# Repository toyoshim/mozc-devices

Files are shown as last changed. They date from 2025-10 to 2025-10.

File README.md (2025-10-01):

Circuit diagrams and firmware source code for Gboard DIY keyboards, previously
known as Google Japanese Input / Gboard April Fools.

This is not an officially supported Google product.

# Products

Please refer to the README in each directory for more details.

<table>
<tr>
<td>

drumset

[Google 日本語入力 ドラムセットバージョン](https://archive.google/drumsetkeyboard/)<br>
[Google Japanese Input Drum set version](https://archive.google/drumsetkeyboard/)

変換の煩わしさを感じさせない思いどおりの日本語入力を提供します。

- [Announce](https://blog.google/intl/ja-jp/products/android-chrome-play/2010_04_google/)
- Release date: Apr 1, 2010
- Source: Not open source

</td>
<td>

morse

[Google 日本語入力 モールスバージョン](http://www.google.co.jp/ime/-.-.html)<br>
[Google Japanese Input Morse version](http://www.google.co.jp/ime/-.-.html)

モールス符号で思いどおりの日本語入力

- [Promotional video](https://www.youtube.com/watch?v=u5AYb778pwA)
- [Announce](https://japan.googleblog.com/2012/04/google.html)
- [Technical details](http://googledevjp.blogspot.jp/2012/06/google.html)
- Release date: Apr 1, 2012
- Source: [/third_party/mozc-morse](./third_party/mozc-morse)

</td>
</tr>
<tr>
<td>

flap

[Google 日本語入力 パタパタバージョン](http://www.google.co.jp/ime/patapata/)<br>
[Google Japanese Input Patapata version](http://www.google.co.jp/ime/patapata/)

もう、なにも覚える必要はありません。
押して離すだけの日本語入力。

- [Promotional video](https://www.youtube.com/watch?v=HzUDAaYMNsA)
- [Announce](https://japan.googleblog.com/2013/04/google-patapata.html)
- [Technical details](http://googledevjp.blogspot.jp/2013/10/google.html)
- Release date: Apr 1, 2013
- Source: [/third_party/mozc-flap](./third_party/mozc-flap)

</td>
<td>

magichand

[Google 日本語入力 マジックハンドバージョン](https://archive.google/ime/m9/)<br>
[Google Japanese Input Magic hand version](https://archive.google/ime/m9/)

マジックハンドでらくらく入力

- [Promotional video](https://www.youtube.com/watch?v=0u1zoaJYAmw)
- [Announce](https://blog.google/intl/ja-jp/products/android-chrome-play/2014_04_m9/)
- Release date: Apr 1, 2014
- Source: Not open source

</td>
</tr>
<tr>
<td>

piropiro

[Google 日本語入力 ピロピロバージョン](https://www.google.co.jp/ime/___o/)<br>
[Google Japanese Input Piropiro version](https://www.google.co.jp/ime/___o/)

もうキーはいらない

- [Promotional video](https://www.youtube.com/watch?v=gAgOnQqyDz0)
- [Announce](https://japan.googleblog.com/2015/04/piropiro.html)
- Release date: Apr 1, 2015
- Source: [/mozc-piropiro](./mozc-piropiro)

</td>
<td>

furikku

[Google 日本語入力 物理フリックバージョン](https://www.google.co.jp/ime/furikku/)<br>
[Google Japanese Input Physical Flick version](https://www.google.co.jp/ime/furikku/)

さわれるフリック

- [Promotional video](https://www.youtube.com/watch?v=5LI1PysAlkU)
- [Announce](https://japan.googleblog.com/2016/04/furikku.html)
- Release date: Apr 1, 2016
- Source: [/mozc-furikku](./mozc-furikku)

</td>
</tr>
<tr>
<td>

puchipuchi

[日本語入力 プチプチバージョン](https://landing.google.co.jp/ime/ooooo/)<br>
[Google Japanese Input Puchi Puchi version](https://landing.google.co.jp/ime/ooooo/)

空気のように、軽やかな入力。

- [Promotional video](https://www.youtube.com/watch?v=RkJZDvHMyTA)
- [Announce](https://japan.googleblog.com/2017/04/ooooo.html)
- Release date: Apr 1, 2017
- Source: [/third_party/mozc-puchi](./third_party/mozc-puchi)

</td>
<td>

nazoru

[Gboard 物理手書きバージョン](https://landing.google.co.jp/tegaki/)<br>
[Gboard Physical Handwriting version](https://landing.google.co.jp/tegaki/)

新しいタイプの手書き入力。

- [Promotional video](https://www.youtube.com/watch?v=guJnFY1R4I0)
- [Announce](https://japan.googleblog.com/2018/04/tegaki.html)
- [Technical details](https://developers-jp.googleblog.com/2018/04/tegaki.html)
- Release date: Apr 1, 2018
- Source: [/mozc-nazoru](./mozc-nazoru)

</td>
</tr>
<tr>
<td>

mageru

[Gboard スプーン曲げバージョン](https://landing.google.co.jp/---o/)<br>
[Gboard Spoon Bending version](https://landing.google.co.jp/---o/)

タネも仕掛けもない、柔軟な入力。

- [Promotional video](https://www.youtube.com/watch?v=DeJY5d14qKs)
- [Announce](https://japan.googleblog.com/2019/04/mageru.html)
- Release date: Apr 1, 2019
- Source:
  - [/mozc-mageru](./mozc-mageru) for firmware, schematics, and PCB layout.
  - [/third_party/mozc-mageru](./third_party/mozc-mageru) for 3D model.

</td>
<td>

yunomi

[Gboard 湯呑みバージョン](https://g.co/yunomi/)<br>
[Gboard yunomi version](https://g.co/yunomi/)

もう、おすしかない。

- [Promotional video](https://www.youtube.com/watch?v=20pC05yisRM)
- [Announce](https://japan.googleblog.com/2021/10/gboard.html)
- Release date: Oct 1, 2021
- Source: [/mozc-yunomi](./mozc-yunomi)

</td>
</tr>
<tr>
<td>

bar

[Gboard 棒バージョン](https://g.co/____)<br>
[Gboard bar version](https://g.co/____)

キーの次はボーです。

- [Promotional video](https://www.youtube.com/watch?v=9G3DWHf1xX0)
- [Announce](https://japan.googleblog.com/2022/10/gboard-2022.html)
- Release date: Oct 1, 2022
- Source: [/mozc-bar](./mozc-bar)

</td>
<td>

caps

[Gboard 帽バージョン](https://g.co/CAPS)<br>
[Gboard CAPS version](https://g.co/CAPS)

入力は、帽険だ。

- [Promotional video](https://www.youtube.com/watch?v=6vib77CUxNM)
- [Announce](https://japan.googleblog.com/2023/10/caps.html)
- Release date: Oct 1, 2023
- Source: [/mozc-caps](./mozc-caps)

</td>
</tr>
<tr>
<td>

double sided

[Gboard 両面バージョン](https://g.co/double-sided)<br>
[Gboard double sided version](https://g.co/double-sided)

表面かと思ったら裏面でした。

- [Promotional video](https://www.youtube.com/watch?v=EHqPrHTN1dU)
- [Announce](https://blog.google/intl/ja-jp/products/android-chrome-play/gboard-2024)
- Release date: Oct 1, 2024
- Source: [/mozc-doublesided](./mozc-doublesided)

</td>
<td>

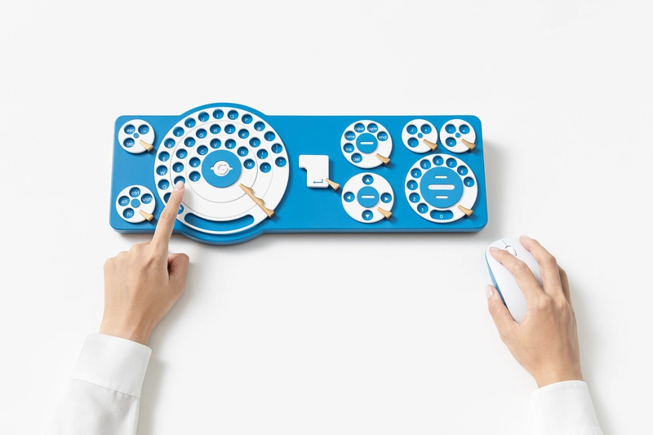
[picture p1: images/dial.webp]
dial


[Gboard ダイヤルバージョン](./mozc-dial/README_ja.md)<br>
[Gboard double sided version](./mozc-dial)

まるくおさめました。

- [Promotional video](https://youtu.be/BgdWyD0cBx4)
- [Announce](https://blog.google/intl/ja-jp/products/android-chrome-play/gboard-2025)
- Release date: Oct 1, 2025
- Source: [/mozc-dial](./mozc-dial)

</td>
</tr>
</table>

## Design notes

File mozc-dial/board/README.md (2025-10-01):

# Board Assembly Guide

For the entire keyboard assembly, please refer to the [Build Guide](../buildguide.md).

## Common to All Editions

### Sensor Board (per board)

#### Bill of Materials

| Ref | Description | Qty | Notes |
|---|---|---|---|
| R1,R3,R5 | Resistor 330Ω | 3 | Through-hole or surface-mount |
| R2,R4,R6 | Not populated | - | |
| U1-3 | Reflective photo sensor RPR-220 | 3 | (e.g., [Reflective Photo Sensor (Photoreflector) RPR-220](https://akizukidenshi.com/catalog/g/g111401/)) |
| J1 | 2.54mm pitch 1x5 pin header | 1 | L-shaped is desirable (e.g., [Pin Header (Male L-type) 1x40 (40P)](https://akizukidenshi.com/catalog/g/g101627/)) |

#### Assembly

This explanation covers the case where all 3 bits are populated. However, for the 9-dial edition, some sensors may only require 1 or 2 bits. In that case, populate only the required number of components from the top (U1). For details, follow the instructions for the 9-dial edition.

Also, before making everything, it is recommended to check if the Gray code plate values can be read properly to reduce rework in case of problems. If it doesn't work well, populate resistors on R2, R4, and R6. For details, see [Reading Sensor Adjustment](#reading-sensor-adjustment).

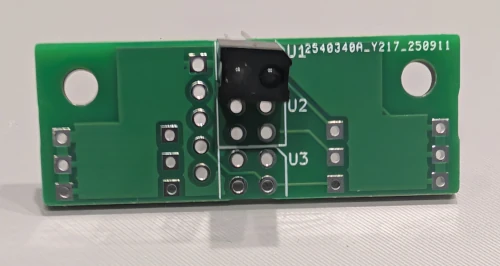
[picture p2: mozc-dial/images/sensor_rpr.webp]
Sensor RPR-220


First, attach the photo sensors from the side where the U1, U2, and U3 markings are visible. Pay close attention to the orientation. The upper right corner is chamfered, so check the marking and the shape of the sensor to ensure they are in the same orientation. After correct placement, cut off the excess leads from the back and solder them.

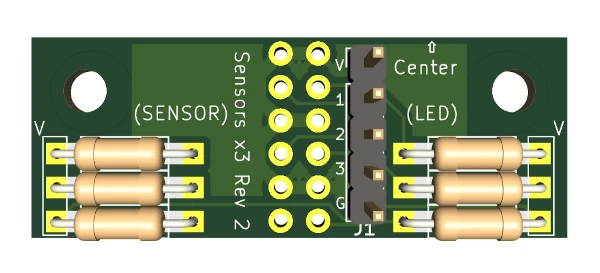
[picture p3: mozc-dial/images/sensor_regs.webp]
Sensor Resistors


On the back side, there are places to attach three resistors on the `(SENSOR)` side and three on the `(LED)` side, as shown in the figure. Both through-hole and chip resistors can be used, so use the parts of your choice. However, even for through-hole types, it is more stable to mount them without passing them through the holes when attaching the dial.

As mentioned earlier, the resistors depend on the adjustment, but it is recommended to leave the `(SENSOR)` side unpopulated and install 330Ω resistors on the `(LED)` side as a standard.

For the 1x5 pin header, using an L-shaped one will fit well in the case.

During assembly, pay attention to the `⇧Center` mark. The inner circumference of the dial will be in the direction of the arrow.

## 1-Dial Edition

This is an introductory edition that uses commercially available general-purpose parts other than the sensor board.

### Parts

- Raspberry Pi Pico: 1
- Sensor board (3-bit populated): 2
- [Unipolar Stepping Motor 28BYJ-48 5V](https://akizukidenshi.com/catalog/g/g113256/): 1
- [Stepping Motor Drive Module [M2003S]](https://www.aitendo.com/product/12366): 1
- Wiring materials: as needed

### Assembly

#### Sensor Board

Assemble two 3-bit populated sensor boards as described in the common section for all dial editions. We will call one `SENSOR L` and the other `SENSOR H`.

Although not a clean example as it was used for experiments, here are examples of mounting both through-hole and chip resistors.

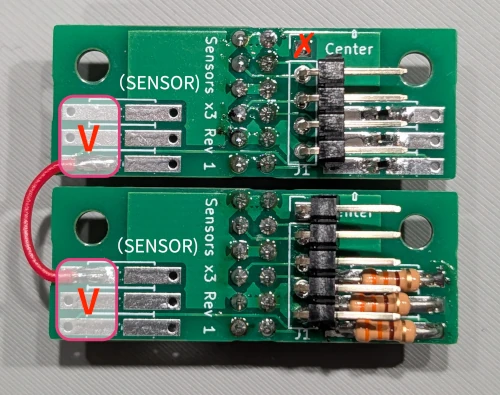
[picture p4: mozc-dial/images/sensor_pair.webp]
Sensor PCB Pair


Each board's pin header has five terminals: `V`, `1`, `2`, `3`, and `G`.
Of these, `V` connects to the 3.3V power supply, but the Raspberry Pi Pico we are using has only one 3.3V output terminal. Therefore, connect the terminal pair where `V` passes on the board, as shown by the red wiring in the photo.
In the diagram for the sensor board, the terminals inside the rectangle labeled `V`, that is, the six outer locations of the resistor patterns, are `V`.

The upper sensor board is `SENSOR L` for the inner circumference, and the lower sensor board is `SENSOR H` for the outer circumference.
Since `V` is interconnected, the `V` at the top-most, inner-most terminal is not needed for this connection.

#### Stepping Motor Drive Module

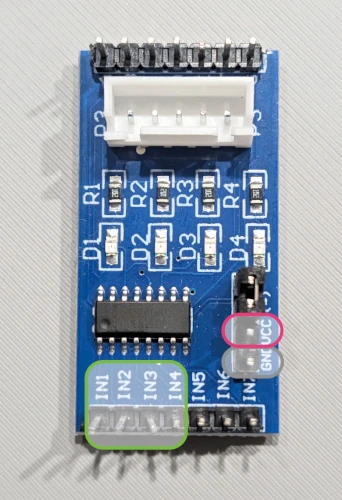
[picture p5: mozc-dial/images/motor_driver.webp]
Motor Driver


The Raspberry Pi Pico's GPIO cannot drive the motor directly, so the 1-dial edition uses a commercially available drive module. Any sink-type driver other than the one specified here will work, and you can also build your own by referring to the circuit of the 9-dial edition.

Taking the one mentioned here as an example, `IN1` to `IN4` enclosed in green are the terminals that receive the outputs `1` to `4` from the Raspberry Pi Pico. `GND` enclosed in black and `VCC` enclosed in red are `G` and `V` respectively.
The motor draws 5V power from the USB bus via the Raspberry Pi Pico. It requires about 0.3A, so the firmware for the 1-dial edition requests the 0.5A upper limit for USB micro.

The white terminal is used for connection with the stepping motor.

#### Raspberry Pi Pico

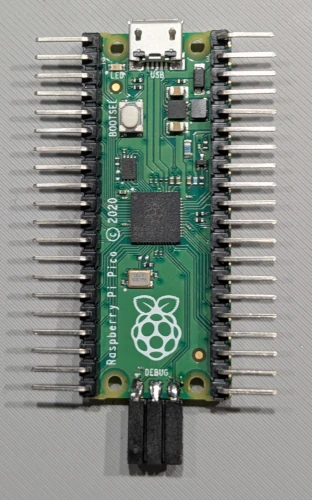
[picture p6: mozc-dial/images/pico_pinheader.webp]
Raspberry Pi Pico - Pin Headers


Attach L-shaped pin headers to a commercially available Raspberry Pi Pico as shown in the photo.
The three DEBUG pins at the bottom of the photo are optional and only needed if you need to develop and debug the firmware.

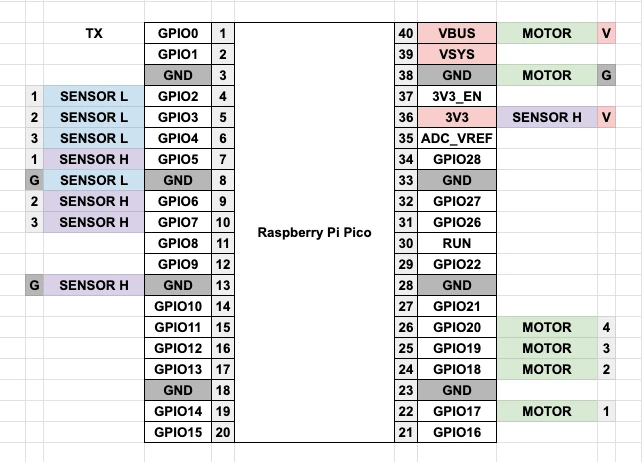
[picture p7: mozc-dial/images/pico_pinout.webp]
Raspberry Pi Pico - Pin Out


The pins used in the 1-dial edition are assigned as shown in the diagram. Connect to SENSOR L, SENSOR H, and MOTOR according to this diagram. When debugging, the standard output is output from TX via UART.

### Firmware Flashing

Follow the general method for the Raspberry Pi Pico. Connect the Raspberry Pi Pico to your PC while holding down the `BOOT` button on the board. A drive named `RPI-RP2` will appear. Copy `firmware/prebuilt/one_dial.uf2` into this drive. If the flashing is successful, the drive will disappear. Your OS may show a warning, but this is not a problem. From now on, when you connect this device to your PC without holding down the `BOOT` button, it will be recognized as a USB keyboard.

## 9-Dial Edition

### Parts

- Main board: 1
- Sensor board (3-bit populated): 6
- Sensor board (2-bit populated): 4
- Sensor board (1-bit populated): 1
- [Unipolar Stepping Motor 28BYJ-48 5V](https://akizukidenshi.com/catalog/g/g113256/): 9
- Wiring materials: as needed

### Main Board

#### Bill of Materials

| Ref | Description | Qty | Notes |
|---|---|---|---|
| C101 | Capacitor 10uF | 1 | |
| C102-121,C202-208,C212,C302-308,C312 | Capacitor 100nF | 36 | |
| C201,C209,C301,C309 | Capacitor 1uF | 4 | |
| C210,C211,C310,C311 | Capacitor 20pF | 4 | |
| J102-103 | 2.54mm pitch 1x3 pin header | 2 | |
| J106-J125 | 2.54mm pitch 1x5 pin header | 20 | |
| J201,J301 | USB TYPE C Receptacle | 2 | |
| R201-202,R301-302 | Resistor 27.4Ω | 4 | |
| R203-204,R303-304 | Resistor 5.1KΩ | 4 | |
| R205,R207,R305,R307 | Resistor 1KΩ | 4 | |
| R206,R306 | Resistor 10KΩ | 2 | |
| SW101,SW201,SW301 | Switch | 3 | |
| U101 | AMS1117 3.3V Regulator | 1 | |
| U102-103,U105,U107,U109 | TBD62083AFNG | 5 | |
| U104,U106,U108,U110 | 74HC238 | 4 | |
| U201,U301 | RP2040 | 2 | |
| U202,U302 | W25Q128JVS | 2 | |
| Y201,Y301 | 12MHz Crystal Oscillator | 2 | |
| N/A | Jumper pin | 2 | |

#### Assembly

Currently, we have released up to the schematics. We will release the Gerber data soon, so please look forward to it!

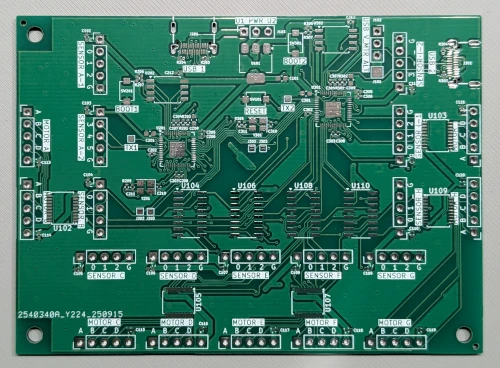
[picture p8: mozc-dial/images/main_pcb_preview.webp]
Coming Soon!!


### Assembly

Attach 1x5 L-shaped pin headers for connecting to the sensor boards to `SENSOR A-L`, `SENSOR A-H`, `SENSOR B`, `SENSOR C`, `SENSOR D`, `SENSOR E`, `SENSOR F`, `SENSOR G`, `SENSOR H`, `SENSOR I-L`, and `SENSOR I-H`.

Attach 1x5 L-shaped pin headers for connecting to the motors to `MOTOR A`, `MOTOR B`, `MOTOR C`, `MOTOR D`, `MOTOR E`, `MOTOR F`, `MOTOR G`, `MOTOR H`, and `MOTOR I`.

Attach a 1x3 pin header to the location marked `U1 PWR U2` and short the `U1` and `PWR` positions with a jumper pin.

Attach a 1x3 pin header to the location marked `USB V_MTR ALT` and short the `USB` and `V_MTR` positions with a jumper pin.

### Sensor Board

Referring to the [Common to All Dial Editions](#common-to-all-dial-editions) section, prepare a total of 11 sensor boards with the following populated bit widths. There is no problem other than an increase in standby power consumption if you populate more bits, so it is also fine to prepare all of them with a 3-bit width.

| Ref | Populated Bit Width |
|---|---|
| SENSOR A-L | 3 |
| SENSOR A-H | 3 |
| SENSOR B | 2 |
| SENSOR C | 3 |
| SENSOR D | 2 |
| SENSOR E | 3 |
| SENSOR F | 3 |
| SENSOR G | 2 |
| SENSOR H | 2 |
| SENSOR I-L | 3 |
| SENSOR I-H | 1 |

## Photo Sensor Adjustment

The photo sensor readings should not vary greatly as they are taken inside the case, but differences may arise due to the brightness of the 3D printing material or the quality of the paper on which the Gray code is printed. If the dial reading is unstable or the rotation does not stop, the sensor value change range may not be within the expected range. In that case, please adjust the sensor paying attention to the following points.

### Reading with RP2040

The sensor value is processed as a digital value by GPIO. Therefore, it needs to be adjusted so that HIGH is in the range of 2.0 - 3.3[V] and LOW is in the range of 0.0 - 0.3[V] when operating at 3.3V.

### LED Sensor Adjustment

If the current flowing through the LED is small, the light emission will be weak, and the amount of light read by the sensor will be insufficient. This will result in higher readings, and the voltage difference between white and black will not be clear. In that case, try changing the three resistors on the `(LED)` side to weaker ones. The standard is adjusted with 330Ω, but with the photo sensor RPR-220 used this time, it will stay within the rated value even if you lower it to about 40Ω. However, it will greatly affect the standby power consumption, so if possible, please adjust with the resistor on the reading sensor side.

### Reading Sensor Adjustment

You can shift the read voltage value by changing the pull-up resistance of the reading sensor. However, if you change it too much, the voltage difference between white and black will become less clear. You can adjust it by populating the three resistors on the `(SENSOR)` side. The standard firmware expects a pull-up of about 50-80KΩ by the RP2040's pull-up. If the voltage does not rise sufficiently with black, it is better to pull-up more strongly with an additional resistor. By following the [Firmware Development Guide](../firmware/README.md) and disabling the RP2040's pull-up, the resistor populated here will become the pull-up resistor. If you do not disable it, it will be pulled up by the combined resistance in parallel. The calculation is a bit complicated, but it may be easier to pull-up in parallel with an additional resistor without changing the firmware if you want to pull-up more strongly.

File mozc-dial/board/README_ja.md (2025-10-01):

# 基板組立ガイド

キーボードの組み立て全体については[ビルドガイド](../buildguide_ja.md)を参照してください。

## 各ダイヤル版共通

### センサー基板（１枚あたり）

#### 部品表

参照名 | 内容 | 数 | 備考
-------- | -------------------- | --- | ---
R1,R3,R5 | 抵抗 330Ω | 3 | スルーホール用でも表面実装用でも可
R2,R4,R6 | 未実装 | - |
U1-3 | 反射型フォトセンサー RPR-220 | 3 | （例：[反射型フォトセンサー(フォトリフレクター) RPR-220](https://akizukidenshi.com/catalog/g/g111401/)）
J1 | 2.54mmピッチ 1x5 ピンヘッダー | 1 | L字のものが望ましい（例：[ピンヘッダー (オスL型) 1×40 (40P)](https://akizukidenshi.com/catalog/g/g101627/)）

#### 実装

この説明では3ビット分全て実装する場合について説明していますが、9ダイヤル版ではセンサーによっては1ビットまたは2ビット分の実装で良い場合があります。その場合は、上(U1)から順に必要な数だけ実装してください。詳しくは9ダイヤル版の説明に従ってください。

また、すべて制作する前に、実際にグレイコード板の値が適切に読み取れるか確認し、問題がない事を確認してから作ると万が一の際の手間が軽減できます。うまくいかない場合にはR2,R4,R6に抵抗を実装します。詳しくは[読み取りセンサー調整](#読み取りセンサー調整)を確認してください。

Sensor RPR-220

まずはU1、U2、U3の印刷が見える方から、フォトセンサーを取りつけます。向きに十分気をつけて下さい。右上の角が面取りされているので、印刷面とセンサーの形状を見て、同じ向きになるよう設置してください。正しく設置したら、裏側から不要な足を切り取りハンダ付けします。

Sensor Registors

裏面はこの図のように`(SENSOR)`側に3つ、`(LED)`側に3つの抵抗を取り付けられるようになっています。抵抗はスルーホール用のものと、チップ抵抗と、いずれのタイプでも取り付けられるようになっているので、お好みいのパーツを使って取り付けてください。ただし、スルーホール用の物でも、穴には通さずに取り付けた方がダイヤル取り付け時に安定します。

抵抗については前述の通り調整に依存しますが、標準では`(SENSOR)`側は未実装、`(LED)`側に330Ωの抵抗を取り付ける事を推奨します。

また、1x5のピンヘッダーについては、L字の物を使うとケースにうまく収まります。

組立時には`⇧Center`マークに注意してください。ダイヤル内周側が矢印の方向になります。

## 1ダイヤル版

センサー基板以外は市販の汎用部品を使う入門版です。

### 部品

- Raspberry Pi Pico: 1個
- センサー基板（3bit実装）: 2個
- [ユニポーラー ステッピングモーター 28BYJ-48 5V](https://akizukidenshi.com/catalog/g/g113256/):
  1個
- [ステッピングモータドライブモジュール [M2003S]](https://www.aitendo.com/product/12366): 1個
- 配線材: 適宜

### 組み立て

#### センサー基板

各ダイヤル版共通で説明したセンサー基板を、3bit実装で2つ組み立てます。 1つを`SENSOR L`、もう1つを`SENSOR H`と呼ぶことにします。

実験時に使用したもので見本としては綺麗なものではありませんが、スルーホール型の抵抗とチップ抵抗それぞれの実装例がこちらになります。

Sensor PCB Pair

それぞれに基板のピンヘッダーには`V`、`1`、`2`、`3`、`G`の5つの端子があります。
このうち`V`は3.3V電源へ繋ぐのですが、今回利用するRaspberry Pi
Picoには3.3V出力端子は1つしかありませんので、写真の赤い配線のように基板上で`V`が通っている端子ペアを接続します。
センサー基板の説明で上げた図において`V`と書かれた長方形の内側にある端子、つまり抵抗用パターンのうち外側の6箇所が`V`になっています。

上側のセンサー基板が`SENSOR L`で内周側、下側のセンサー基板が`SENSOR H`で外周側になります。
`V`を相互接続したので、一番上の最も内側にあたる端子の`V`は今回接続不要となります。

#### ステッピングモータドライブモジュール

Motor Driver

Raspberry Pi
PicoのGPIOでは直接モーターをドライブできないため、1ダイヤル版では市販のドライブモジュールを流用します。シンクタイプのドライバなら今回指定したもの以外でも構いませんし、9ダイヤル版の回路を参考に自作する事も可能です。

今回参考に上げた物を例にすると、緑で囲んだ`IN1`〜`IN4`がRaspberry Pi
Picoからの出力の`1`〜`4`を受ける端子になります。黒で囲んだ`GND`と赤で囲んだ`VCC`がそれぞれ`G`と`V`です。
モーターの方はUSBバスから5Vの電源をRaspberry Pi
Pico経由で引き込みます。0.3Aくらい必要となるため、1ダイヤル版のファームウェアではUSB microでの上限である0.5Aを要求しています。

白い端子はステッピングモータとの接続に使います。

#### Raspberry Pi Pico

Raspberry Pi Pico - Pin Headers

市販のRaspberry Pi Picoに対して、写真のようにL字のピンヘッダーを取り付けます。
写真で下の方にあるDEBUG用のピン3つについては、ファームウェアの開発とデバッグが必要な場合のみで構いませんので、お好みで取り付けてください。

Raspberry Pi Pico - Pin Out

1ダイヤル版で使うピンについては、図のような割り当てになっています。この図に従って、SENSOR L、SENSOR
H、MOTORと接続します。デバッグ時の標準出力をUARTから出力する場合はTXから出力されます。

### ファームウェア書き込み

Raspberry Pi Picoの一般的な方法に従います。Raspberry Pi
Pico基板上の`BOOT`ボタンを押しながらPCに接続すると`RPI-RP2`という名前のドライブが出現するので、`firmware/prebuilt/one_dial.uf2`をこのドライブの中にコピーします。正しく書き込みができた場合ドライブが消えます。OSによって警告が表示されますが問題ありません。これ以降、このデバイスを`BOOT`ボタンを押さずにPCに接続した場合は、USBキーボードとして認識されるようになります。

## 9ダイヤル版

### 部品

- メイン基板: 1個
- センサー基板（3bit実装）: 6個
- センサー基板（2bit実装）: 4個
- センサー基板（1bit実装）: 1個
- [ユニポーラー ステッピングモーター 28BYJ-48 5V](https://akizukidenshi.com/catalog/g/g113256/):
  9個
- 配線材: 適宜

### メイン基板

#### 部品表

参照名 | 内容 | 数
------------------------------------ | ----------------------- | ---
C101 | コンデンサ 10uF | 1
C102-121,C202-208,C212,C302-308,C312 | コンデンサ 100nF | 36
C201,C209,C301,C309 | コンデンサ 1uF | 4
C210,C211,C310,C311 | コンデンサ 20pF | 4
J102-103 | 2.54mmピッチ 1x3 ピンヘッダ | 2
J106-J125 | 2.54mmピッチ 1x5 ピンヘッダ | 20
J201,J301 | USB TYPE C Receptacle | 2
R201-202,R301-302 | 抵抗 27.4Ω | 4
R203-204,R303-304 | 抵抗 5.1KΩ | 4
R205,R207,R305,R307 | 抵抗 1KΩ | 4
R206,R306 | 抵抗 10KΩ | 2
SW101,SW201,SW301 | スイッチ | 3
U101 | AMS1117 3.3V レギュレーター | 1
U102-103,U105,U107,U109 | TBD62083AFNG | 5
U104,U106,U108,U110 | 74HC238 | 4
U201,U301 | RP2040 | 2
U202,U302 | W25Q128JVS | 2
Y201,Y301 | 12MHz Crystal Oscilator | 2
N/A | ジャンパーピン | 2

#### 実装

現在、回路図まで公開しています。近日中にガーバーデータを公開しますのでお楽しみに！

Coming Soon!!

### 組み立て

`SENSOR A-L`、`SENSOR A-H`、`SENSOR B`、`SENSOR C`、`SENSOR D`、`SENSOR E`、`SENSOR F`、`SENSOR G`、`SENSOR H`、`SENSOR I-L`、`SENSOR I-H`それぞれに、センサー基板との接続に用いる1x5のL字型ピンヘッダを取り付けます。

`MOTOR A`、`MOTOR B`、`MOTOR C`、`MOTOR D`、`MOTOR E`、`MOTOR F`、`MOTOR G`、`MOTOR H`、`MOTOR I`についてはモーターとの接続に用いる1x5のL字型ピンヘッダを取り付けます。

`U1 PWR U2`と書かれた箇所に1x3のピンヘッダを取り付け、ジャンパーピンで`U1`と`PWR`の位置をショートします。

`USB V_MTR ALT`と書かれた箇所に1x3のピンヘッダと取り付け、ジャンパーピンで`USB`と`V_MTR`の位置をショートします。

### センサー基板

[各ダイヤル版共通](#各ダイヤル版共通)の説明を参照して、合計11個のセンサー基板をそれぞれ以下の実装ビット幅で用意します。多めに実装する分には待機時消費電力の増加以外は問題ないので、全てを3ビット幅で用意してしまっても問題はありません。

参照名 | 実装ビット幅
---------- | ------
SENSOR A-L | 3
SENSOR A-H | 3
SENSOR B | 2
SENSOR C | 3
SENSOR D | 2
SENSOR E | 3
SENSOR F | 3
SENSOR G | 2
SENSOR H | 2
SENSOR I-L | 3
SENSOR I-H | 1

## フォトセンサーの調整について

フォトセンサーの読み取り値は、ケース内での読み取りになるため大きな差は出にくいはずですが、3Dプリント素材の明るさの違いや、グレイコードを印刷した紙の質などによって違いが出てくる可能性があります。ダイヤルの読み取りが安定しない、回転が止まらないなどの症状が出ている場合にはセンサー値の変化範囲が想定内に収まっていない可能性がありますので、以下の点に注意してセンサーの調整をしてください。

### RP2040での読み取り

センサーの値はGPIOでデジタル値として処理しています。そのため、3.3V稼働時にHIGHは2.0 - 3.3[V]、LOWは0.0 -
0.3[V]の範囲に収まるよう調整されている必要があります。

### LEDセンサー調整

LEDに流れる電流が少ないと発光も弱くなり、センサーで読み取る光量も不足します。そのため、読み取り値が高くなり、白と黒で電圧差がはっきりとでなくなってきます。その場合、`(LED)`と書かれた側にある3つの抵抗を弱いものに変えてみてください。標準では330Ωで調整していますが、今回用いているフォトセンサーRPR-220では40Ωくらいまで下げても定格内に収まります。ただし、待機時の消費電力に大きく影響しますので、可能なら読み取りセンサー側の抵抗で調整してください。

### 読み取りセンサー調整

読み取りセンサーのpull-up抵抗値を変える事で、読み取る電圧値をシフトさせる事ができます。ただし、大きく変えすぎるとやはり白と黒の電圧差が出にくくなります。`(SENSOR)`と書かれた側にある3つの抵抗を実装する事で調整できます。標準のファームウェアではRP2040のpull-upにより、およそ50-80KΩでpull-upされる事を期待しています。黒で十分に電圧が上がらない場合は、追加の抵抗でより強くpull-upすると良いでしょう。[ファームウェア開発ガイド](../firmware/README_ja.md)に従いRP2040のpull-upを無効化すると、ここに実装した抵抗がそのままpull-up抵抗になります。無効化しない場合は並列接続での合成抵抗でpull-upする事になります。計算が少し煩雑ですが、より強くpull-upする分にはファームウェアを変えずに追加の抵抗で並列でpull-upする方が簡単かもしれません。

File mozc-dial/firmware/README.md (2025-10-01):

# Firmware Development Guide

For the entire keyboard assembly, please refer to the [Build Guide](../buildguide.md).

## Directory List

- prebuilt/ : Pre-built firmware for each board
- common/ : Source files for libraries used in common by each board
- main/ : Source files and project for the 9-dial edition main chip
- sub/ : Source files and project for the 9-dial edition sub chip
- one_dial/ : Source files and project for the 1-dial edition Raspberry Pi Pico

## Pre-built Firmware

We have included pre-built firmware under `prebuilt/`, so you can use them as is if no changes are needed.

Use `main.uf2` and `sub.uf2` for the 9-dial edition, and `one_dial.uf2` for the 1-dial edition.

## Guide to Developing Your Own Firmware

Install [Visual Studio Code](https://code.visualstudio.com/) and add the [Raspberry Pi Pico extension](https://marketplace.visualstudio.com/items?itemName=raspberry-pi.raspberry-pi-pico).

From the `Raspberry Pi Pico Projects` extension in the Activity Bar, use `Import Project` to open each project's directory.
If you are using the extension for the first time, the development environment installation will begin. Once the project is imported, you can develop using `CMake` and `Run and Debug` in the Activity Bar.

As with the official Pico series boards, the 9-dial edition has `SWCLK` and `SWDIO` land pairs labeled `SWC/D` on the board for each chip. By preparing development equipment that supports SWD, such as the official Debug Probe, you can perform step execution in the editor.

### Standard Output

On the 9-dial edition, there are lands labeled `TX1` for the main chip and `TX2` for the sub-chip on the board. With the standard settings, the standard output is output from these pins as UART at a speed of 115200.

On the other hand, by changing `pico_enable_stdio_uart` to `0` and `pico_enable_stdio_semihosting` to `1` in `CMakeLists.txt`, you can switch the output to go through the debugger. This is convenient as you don't need to wire TX, but be aware that the operation will stop at the output point if debugger support is not enabled. It will also stop when the debugger is not attached, so it cannot be used for release builds. Debugger support can be enabled with `monitor arm semihosting enable`, but it is tedious to set it every time you start the debugger, so it is convenient to register it in each command setting in `.vscode/launch.json` as follows.

```
"postLaunchCommands": [
    "monitor arm semihosting enable"
]
```

### Using PICO W or PICO 2 (W)

The 1-dial edition is set to use the official Raspberry Pi Pico board, but you can support other boards by changing the board setting from `pico` to `pico_w`, `pico2`, `pico2_w`, etc. in `set(PICO_BOARD pico CACHE STRING "Board type")` in `CMakeFiles.txt`. You should also be able to support 3rd party boards with `none`, etc.

### About EEPROM

Since the board setting for the 9-dial edition is `none`, a general-purpose driver for EEPROM will be included with a prescaler setting of 4. This should work with most EEPROMs. If you are using the reference parts, we have confirmed that the driver for W25Q080 works with a prescaler setting of 2, similar to the official board. By creating a `board_name.h` in `~/.pico-sdk/sdk/2.2.0/src/boards/include/boards/` and defining

```
#define PICO_BOOT_STAGE_2_CHOOSE_W25Q080 1
#define PICO_FLASH_SPI_CLKDIV 2
```

and specifying it in the board settings of `CMakeFiles.txt`, you can optimize EEPROM access via QSPI in case of a cache miss and draw out further performance.

### About Sensor Adjustment

By default, the sensor is pulled up by an internal resistor. If you want to adjust it by pulling up with an external resistor, change `gpio_pull_up(gpio);` to `gpio_disable_pulls(gpio);` in `PhotoSensor::PhotoSensor()` in `photo_sensor.cc`.

Alternatively, it is also possible to pull up with a combined resistance of the internal and external resistors while the internal resistor is enabled. In this case, the internal resistor has a nominal value of 50-80KΩ and is connected in parallel with the external resistor.

For details, please check the [Board Assembly Guide](../board/README.md).

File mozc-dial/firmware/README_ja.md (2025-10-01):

# ファームウェア開発ガイド

キーボードの組み立て全体については[ビルドガイド](../buildguide_ja.md)を参照してください。

## ディレクトリ一覧

- prebuilt/ : 各ボード向けに事前にビルドしたファームウェア
- common/ : 各ボード共通で用いられるライブラリのソースファイル
- main/ : 9ダイヤル版メインチップ用のソースファイルとプロジェクト
- sub/ : 9ダイヤル版サブチップ用のソースファイルとプロジェクト
- one_dial/ : 1ダイヤル版 Raspberry Pi Pico用のソーとファイルとプロジェクト

## 事前にビルドしたファームウェア

`prebuilt/`以下に事前にビルドしたファームウェアを収めていますので、変更が不要の場合はこれらをそのまま用いることができます。

9ダイヤル板は`main.uf2`と`sub.uf2`を、1ダイヤル板は`one_dial.uf2`を使用します。

## 独自のファームウェア開発の手引き

[Visual Studio Code](https://code.visualstudio.com/) をインストールし、[Raspberry Pi Pico拡張](https://marketplace.visualstudio.com/items?itemName=raspberry-pi.raspberry-pi-pico) を追加します。

Activity Barの`Raspberry Pi Pico Projects`の拡張機能から`Import Project`を使い、各プロジェクトのディレクトリを開いてください。
拡張をはじめて使う場合、開発環境のインストールが始まります。プロジェクトが取り込まれると、Activity Barの`CMake`や`Run and Debug`を使って開発できるようになります。

公式のPicoシリーズボードに搭載されているように、9ダイヤル板でも基板上に`SWC/D`と書かれた`SWCLK`と`SWDIO`のランドペアがそれぞれのチップごとに用意されています。公式のDebug Probe等のSWDをサポートした開発機材を用意する事で、エディタ上でステップ実効等が可能です。

### 標準出力について

9ダイヤル板では基板上にメインチップ用の`TX1`、サブチップ用の`TX2`と書かれたランドが用意されており、標準の設定では標準出力はこれらのピンから速度115200のUARTとして出力されています。

一方で`CMakeLists.txt`の`pico_enable_stdio_uart`を`0`に、`pico_enable_stdio_semihosting`を`1`に変更する事で、出力をデバッガ経由に切り替える事ができます。TXを配線せずに済むので便利ですが、デバッガのサポートを有効にしないと出力のところで動作停止するので注意が必要です。デバッガがアタッチされていない時も同様に停止するので、リリースビルドには使えません。デバッガのサポートは`monitor arm semihosting enable`で有効に出来ますが、デバッガ起動ごとに毎回設定するのは大変なので、`.vscode/launch.json`の各コマンド設定内に以下のように登録しておくと便利です。

```
"postLaunchCommands": [
    "monitor arm semihosting enable"
]
```

### PICO WやPICO 2 (W)の利用

1ダイヤル板は公式のRaspberry Pi Picoボードを使うように設定してありますが、`CMakeFiles.txt`内の`set(PICO_BOARD pico CACHE STRING "Board type")`のところでボード設定を`pico`から`pico_w`、`pico2`、`pico2_w`等に変更する事で他のボードにも対応できるかと思います。3rd party製のボードについても`none`等で対応できるかと思います。

### EEPROMについて

9ダイヤル版はボード設定を`none`にしているので、EEPROMについては汎用のドライバが分周4で組み込まれます。これでだいたいのEEPROMで動作するはずです。リファレンスの部品を使っている場合は、公式ボードと同様にW25Q080用のドライバが分周2で動作する事を確認しています。`~/.pico-sdk/sdk/2.2.0/src/boards/include/boards/`に`ボード名.h`を作成し、その中で

```
#define PICO_BOOT_STAGE_2_CHOOSE_W25Q080 1
#define PICO_FLASH_SPI_CLKDIV 2
```

などを定義し、`CMakeFiles.txt`のボード設定で指定する事で、キャッシュミス時のQSPI経由でのEEPROMアクセスを最適化し、さらなる性能を引き出す事も可能です。

### センサーの調整について

標準ではセンサーは内部抵抗でpull-upされています。外部抵抗によりpull-upで調整したい場合、`photo_sensor.cc`の`PhotoSensor::PhotoSensor()`内にある`gpio_pull_up(gpio);`を`gpio_disable_pulls(gpio);`に変更してください。

あるいは、内部抵抗を有効にしたまま外部抵抗との合成抵抗でpull-upする事も可能です。この場合、内部抵抗は公称値で50-80KΩ、外部抵抗とは並列接続になります。

詳細は[基板組立ガイド](../board/README_ja.md)を確認してください。

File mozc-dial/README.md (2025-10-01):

[Japanese version](./README_ja.md) is available.

# Gboard Dial Version

This directory contains the design data and firmware for the Gboard Dial Version, released on October 1, 2025.
The Gboard Dial Version is not an official Google product.

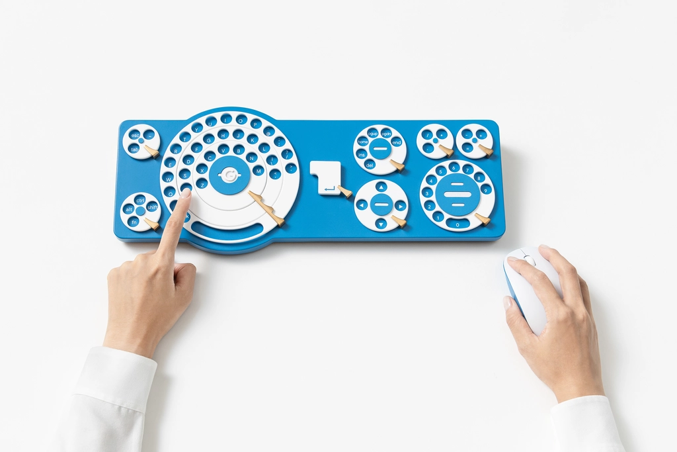
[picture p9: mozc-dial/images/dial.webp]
Gboard dial version


**We've made things well-rounded.**

"Keyboards are boring if you can only type on them."

In response to feedback from our users,

we have created a keyboard that you can turn.

The Gboard Dial Version,

realizing text input by rotation.

## Let's build it

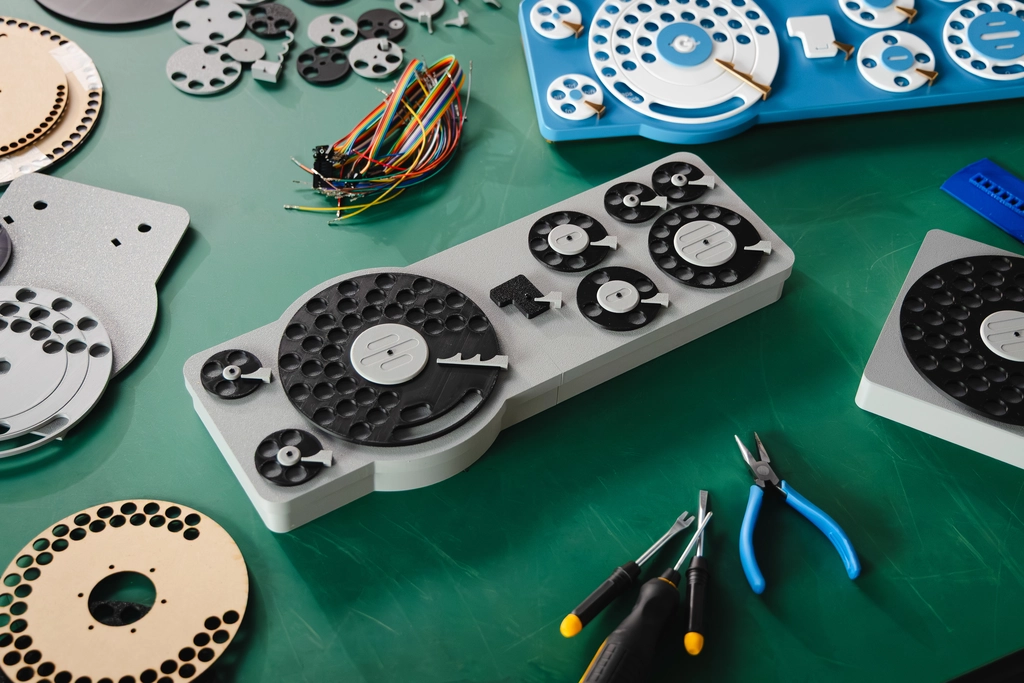
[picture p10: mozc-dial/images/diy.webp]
Gboard DIY


This year again, we are releasing 3D printing model data, board data, and firmware.

[Click here for the build guide](./buildguide.md)

## There's also a non-rotating Gboard

For those who are accustomed to conventional typing input,

we also offer the standard version of Gboard.

It provides a comfortable input experience

in conjunction with various Google services

such as voice input and translation functions.

[Available on Google Play](https://play.google.com/store/apps/details?id=com.google.android.inputmethod.latin)<br>
[Available on the App Store](https://apps.apple.com/us/app/gboard-the-google-keyboard/id1091700242)

## [Other versions](https://github.com/google/mozc-devices)

## License

See [LICENSE](../LICENSE) file in this directory.

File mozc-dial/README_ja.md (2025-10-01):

Gboard[English version](./README.md) is available.

# Gboard ダイヤルバージョン

このディレクトリは 2025 年 10 月 1 日にリリースされた Gboard ダイヤルバージョンの設計データとファームウエアを含んでいます。
Gboard ダイヤルバージョンは正式な Google 製品ではありません。

Gboard dial version

**まるくおさめました。**

「キーボードは打つだけじゃつまらない」

そんなユーザーのみなさまの声に応えて

まわす事ができるキーボードを作りました。

回転による文字入力を実現した、

Gboard ダイヤルバージョン

## 作ってみよう

Gboard DIY

今年も 3D プリント用モデルデータ、基板データ、ファームウエアを公開しています。

[ビルドガイドはこちら](./buildguide_ja.md)

## まわらないGboardもあります

いままでの打つ文字入力に慣れ親しんだ方には、

通常版の Gboard もご用意しております。

音声入力や翻訳機能など

Google の各種サービスと連携した

快適な入力体験を提供します。

[Google Play で公開中](https://play.google.com/store/apps/details?id=com.google.android.inputmethod.latin&hl=ja)<br>
[App Store で公開中](https://apps.apple.com/jp/app/id1091700242)

## [その他のバージョン](https://github.com/google/mozc-devices)

## ライセンス

このディレクトリに置かれた [LICENSE](../LICENSE) ファイルを参照してください。

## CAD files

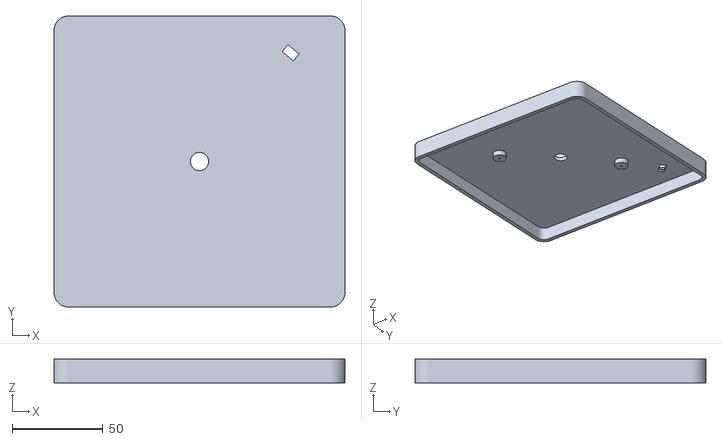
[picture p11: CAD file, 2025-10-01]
mozc-dial/stls/one_dial/case_top.stl
160.0 x 160.0 x 13.0

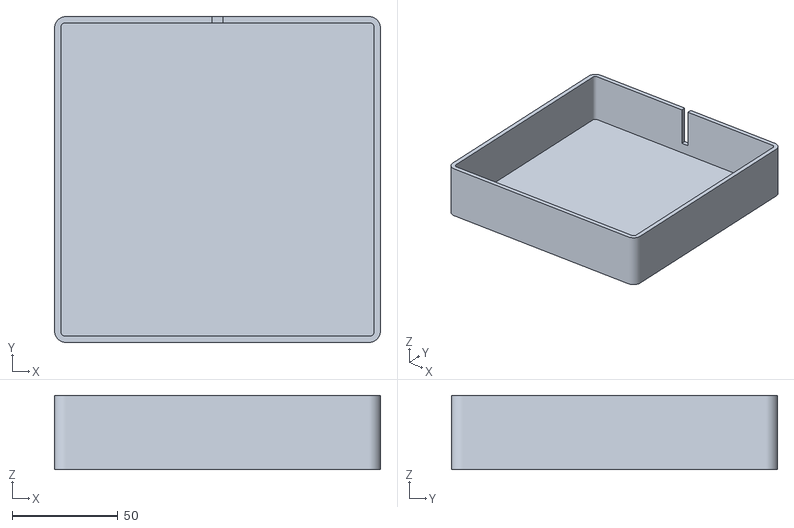
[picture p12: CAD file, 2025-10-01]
mozc-dial/stls/one_dial/case_bottom.stl
154.0 x 154.0 x 35.0

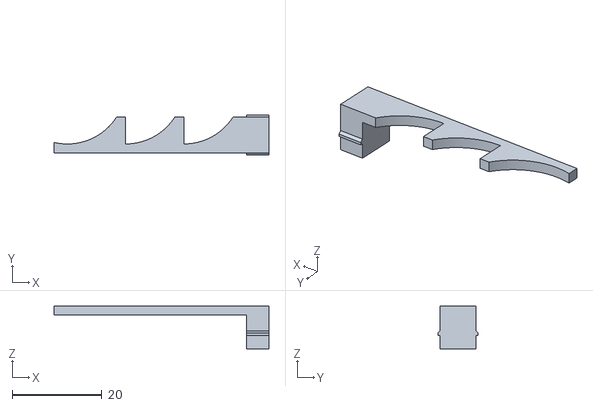
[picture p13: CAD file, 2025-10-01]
mozc-dial/stls/one_dial/end3.stl
48.0 x 9.00 x 9.50

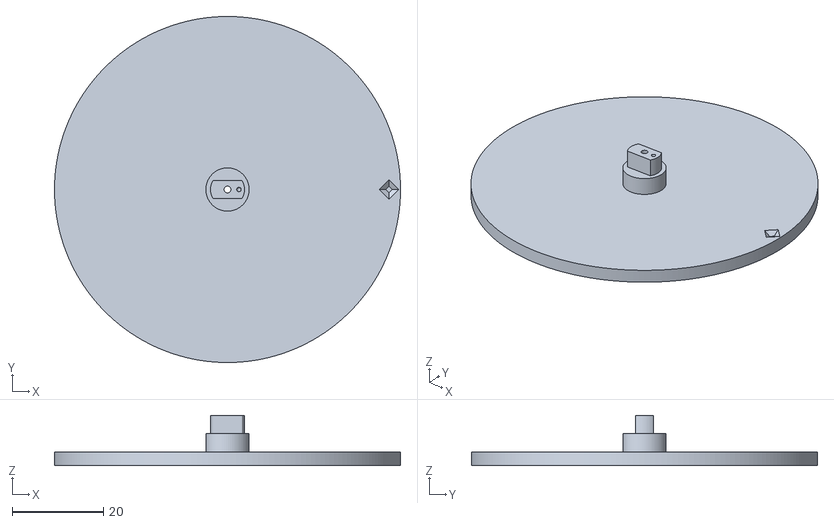
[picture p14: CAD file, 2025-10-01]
mozc-dial/stls/one_dial/encoder.stl
76.0 x 76.0 x 11.0

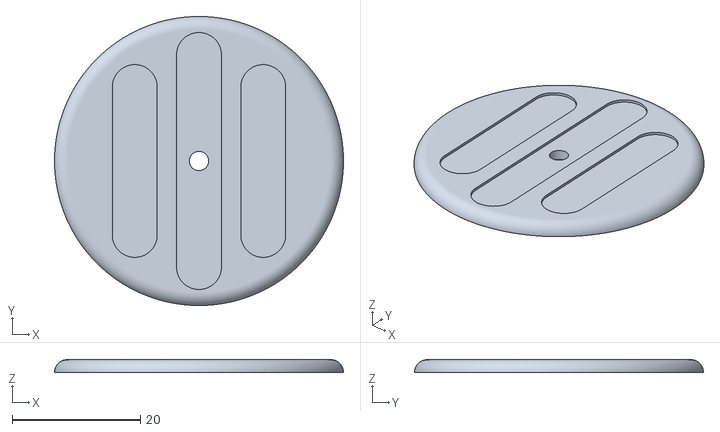
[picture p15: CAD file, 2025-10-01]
mozc-dial/stls/one_dial/dial_cap.stl
45.0 x 45.0 x 2.00

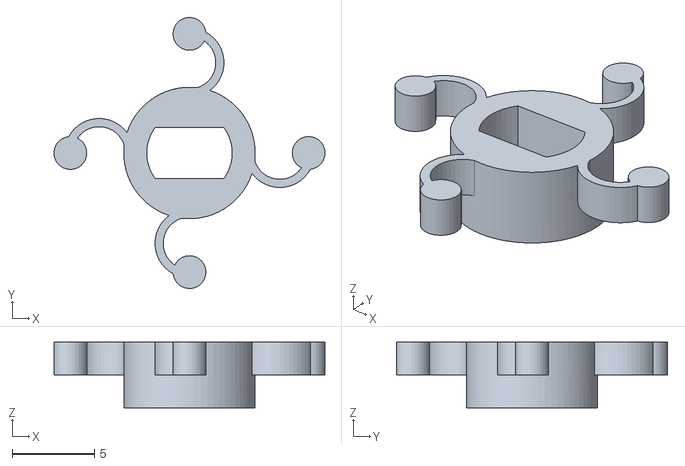
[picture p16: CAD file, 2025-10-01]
mozc-dial/stls/one_dial/clutch.stl
16.5 x 16.5 x 4.00

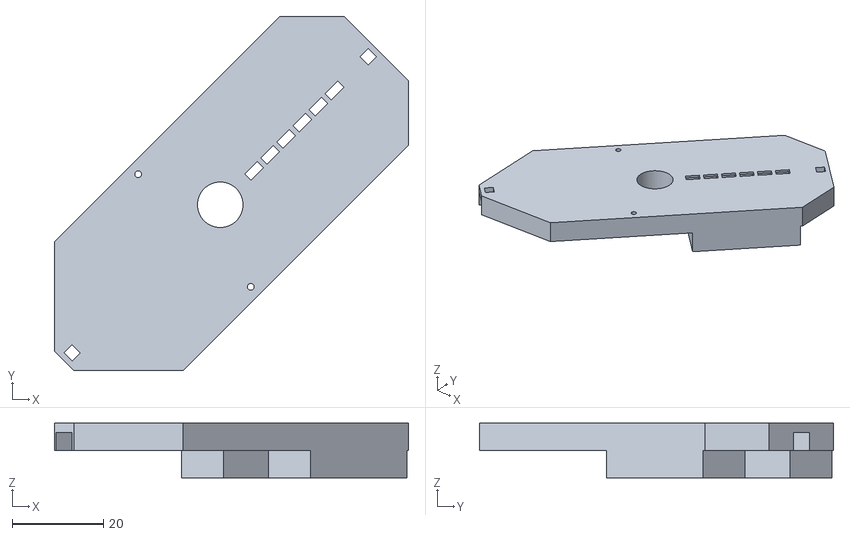
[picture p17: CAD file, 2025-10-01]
mozc-dial/stls/one_dial/cover.stl
77.8 x 77.8 x 12.0

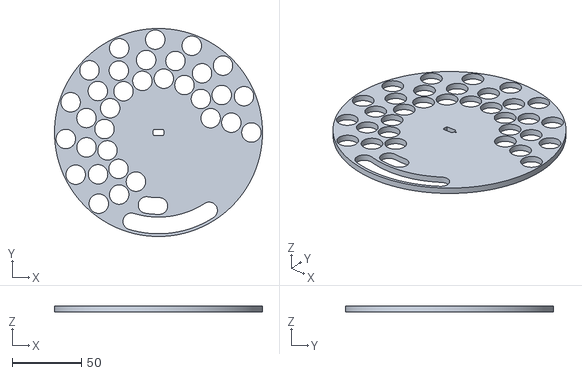
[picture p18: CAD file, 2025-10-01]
mozc-dial/stls/one_dial/dial.stl
150.0 x 150.0 x 4.00

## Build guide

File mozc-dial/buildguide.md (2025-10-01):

# Build Guide

Gboard DIY

[Read the project overview first](./README.md)

## File List

- stls/ : STL files for the case
- stls/one_dial/ : For the 1-dial edition
- stls/full/ : For the 9-dial edition (Stay tuned!)
- pattern/ : Encoder pattern files
- board/ : KiCad schematics and board layout data
- board/gerber/ : Gerber data for PCB production and assembly
- firmware/ : Firmware development resources for Raspberry Pi Pico C/C++ SDK
- firmware/prebuilt : Pre-built firmware binaries

## Assembly

We have prepared a 1-dial edition, which is easier to assemble with only one dial, and a full edition with nine dials.

### 1-Dial Edition

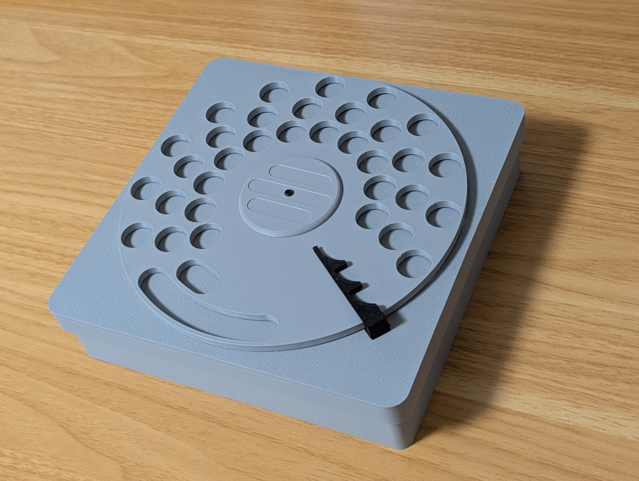
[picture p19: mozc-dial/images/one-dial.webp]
1-Dial Edition


#### Required Parts

- 3D printed parts (1 of each)
  - Bottom case (case_bottom.stl)
  - Top case (case_top.stl)
  - Dial (dial.stl)
  - Dial cap (dial_cap.stl)
  - Encoder (encoder.stl)
  - Clutch (clutch.stl)
  - Fixing cover (cover.stl, print in a color close to white, such as gray)
  - Triple claw (end3.stl)
- Encoder pattern pattern/one_dial.svg
- Screws
  - 12 self-tapping screws, 2mm diameter, 4mm length
  - 2 washers
- Electronic parts ([see the board directory for details](./board/README.md))
  - 1 [Firmware installed](./firmware/README.md) Raspberry Pi Pico
  - 2 assembled sensor boards
  - 1 [Unipolar Stepping Motor 28BYJ-48 5V](https://akizukidenshi.com/catalog/g/g113256/)
  - 1 [Motor driver module](https://www.aitendo.com/product/12366)
  - Wiring materials: as needed

#### Step 1: Create the Encoder

Print the [pattern file](./pattern/one_dial.svg) on copy paper at actual size.
Place the encoder part on top with the printed side down, glue it, and cut around the perimeter and the center.

Align the ◆ mark on the encoder part with the ▼ mark on the paper.

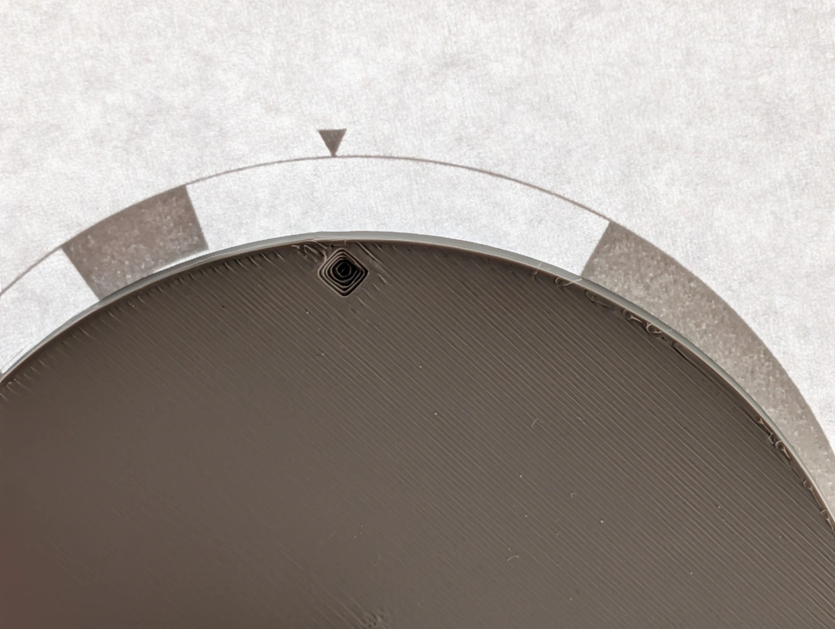
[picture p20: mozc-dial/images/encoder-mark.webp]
Align the marks


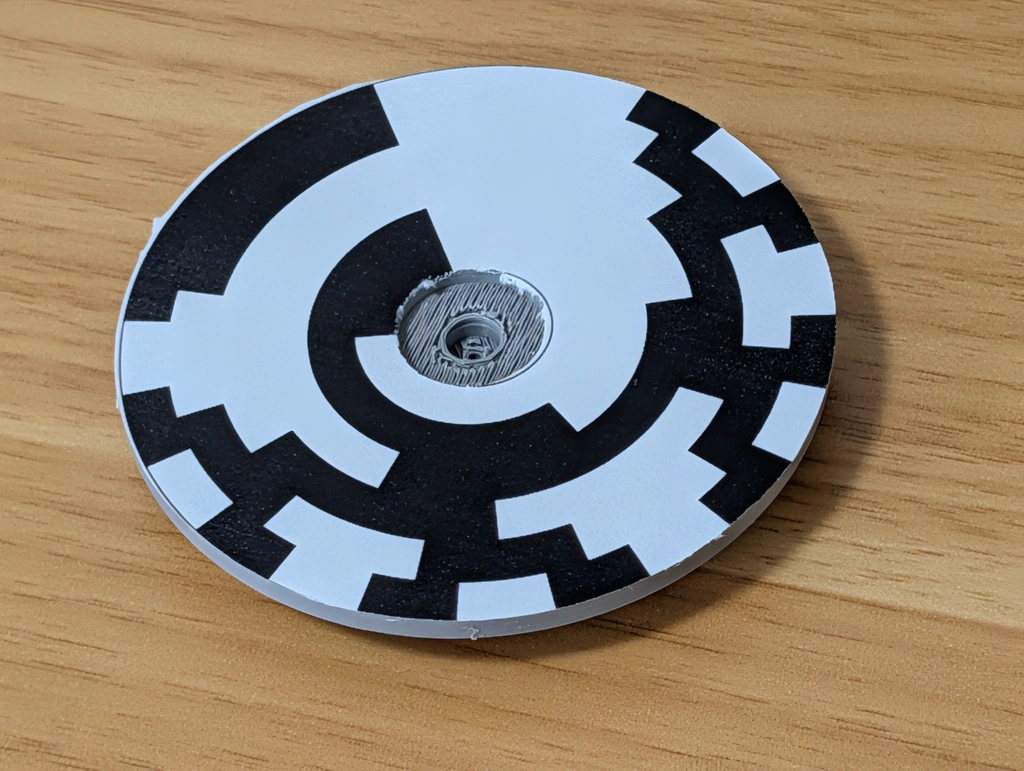
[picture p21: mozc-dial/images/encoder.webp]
Assembled encoder


#### Step 2: Assemble the Cover Module

The cover needs to be printed in a non-transparent color because it uses a photosensor.
In the prototype, we used gray PLA.
You may need to adjust the resistance of the sensor board for other colors.

Screw the two sensor boards to the back.

Also, screw the stepping motor to the back.

We call the sensor board near the motor as "Sensor L" board and other one as "Sensor H" board.

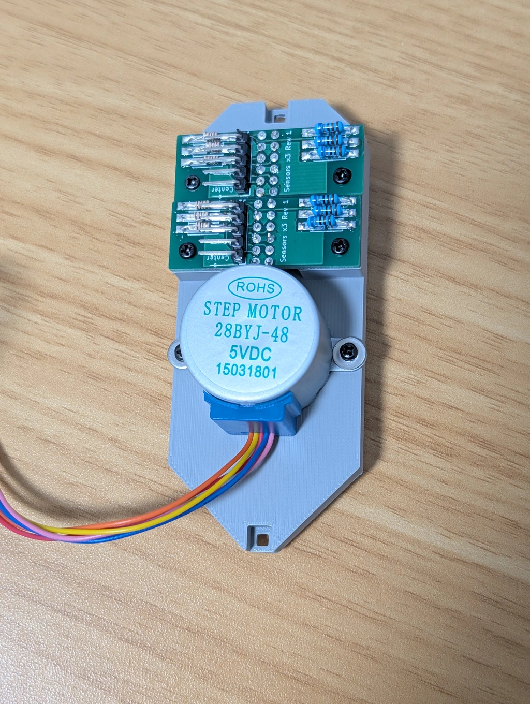
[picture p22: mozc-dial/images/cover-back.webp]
Back side


Attach the clutch to the motor shaft protruding from the front.

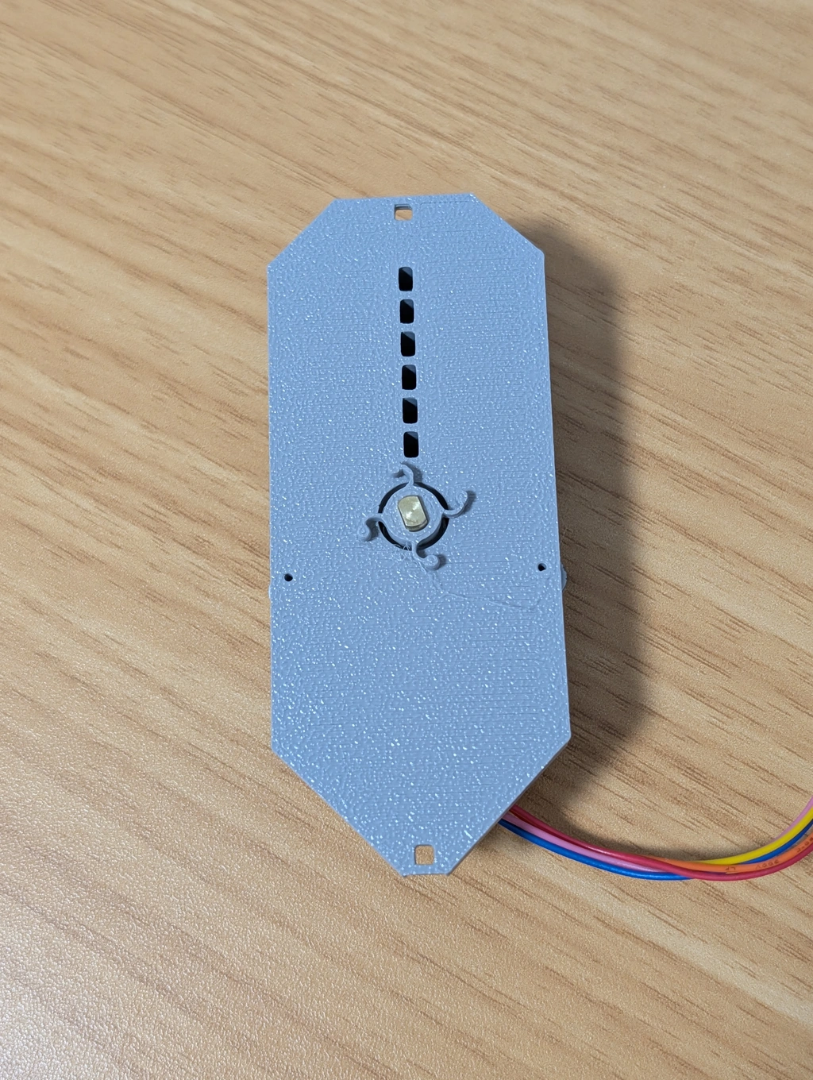
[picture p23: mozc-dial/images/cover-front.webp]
Front side


#### Step 3: Attach to the Case

From the back, attach the encoder and then the cover.
Refer to the photo below for the orientation of the cover.

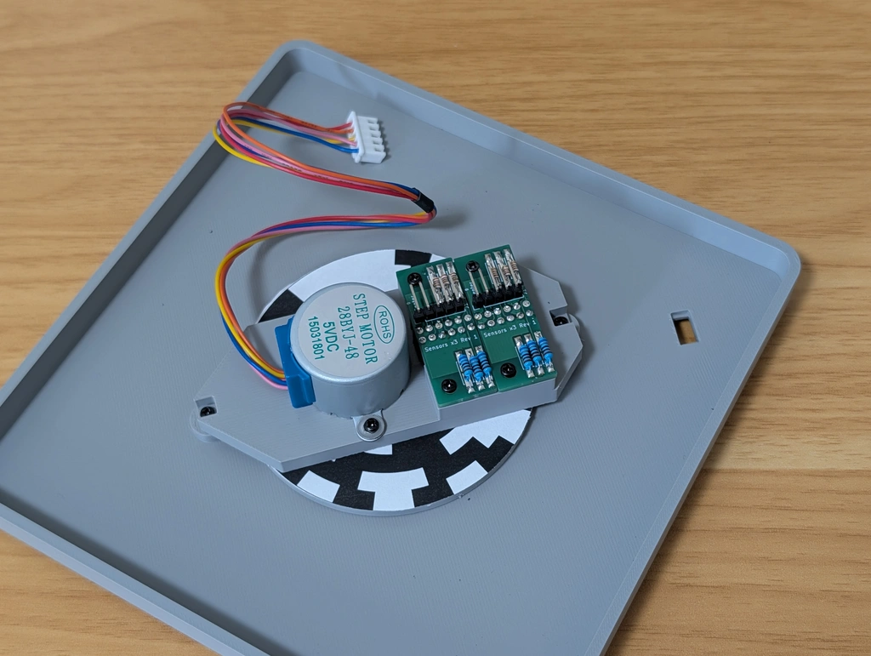
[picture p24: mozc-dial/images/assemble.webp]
Assembly


From the front, attach the dial and cap to the shaft.
There are small marks on the dial and shaft, so align them.

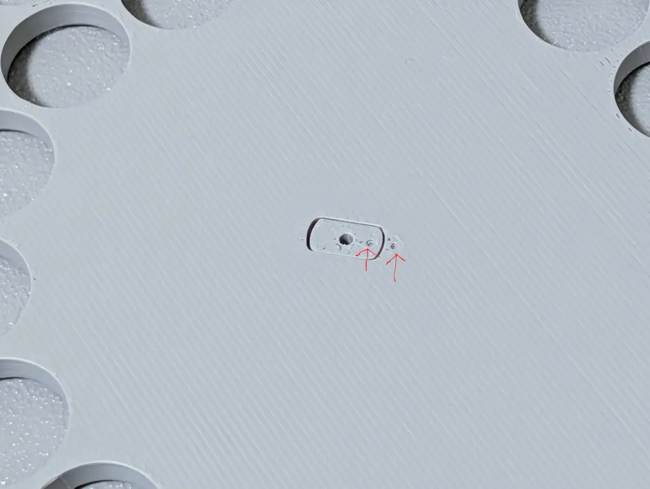
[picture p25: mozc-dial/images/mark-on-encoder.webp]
Marks on the dial


Attach the dial cap from the top and secure it with a screw.

Overall view

#### Step 4: Wiring

Attach the sensor board and motor driver to the Raspberry Pi Pico.

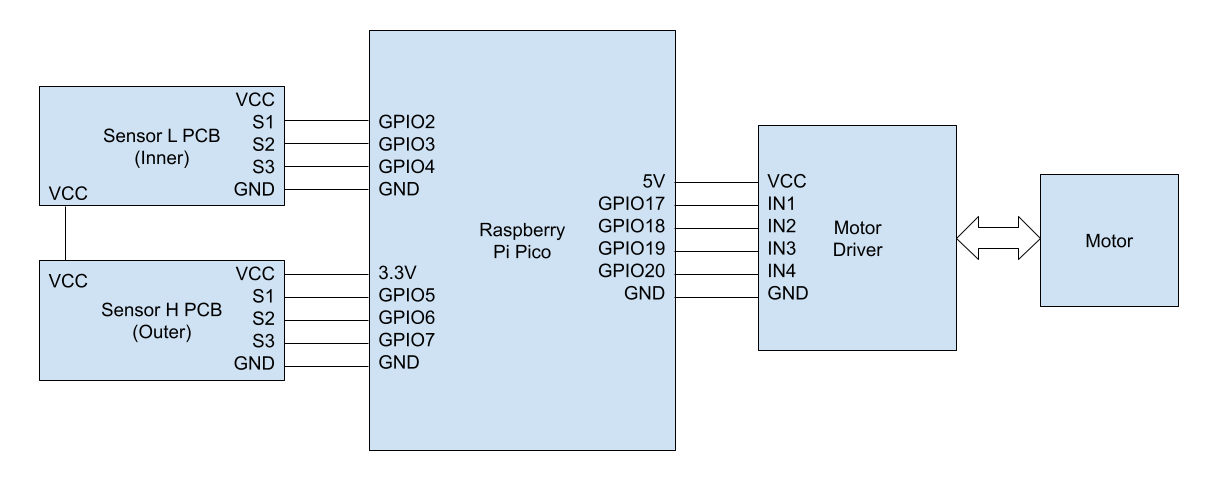
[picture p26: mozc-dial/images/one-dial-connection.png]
Wiring


Please check [board assembly guide](./board/README.md) for details.

Secure the board to the edge of the bottom case with double-sided tape or similar.

### 9-Dial Edition

**The 9-dial edition is currently under adjustment.**

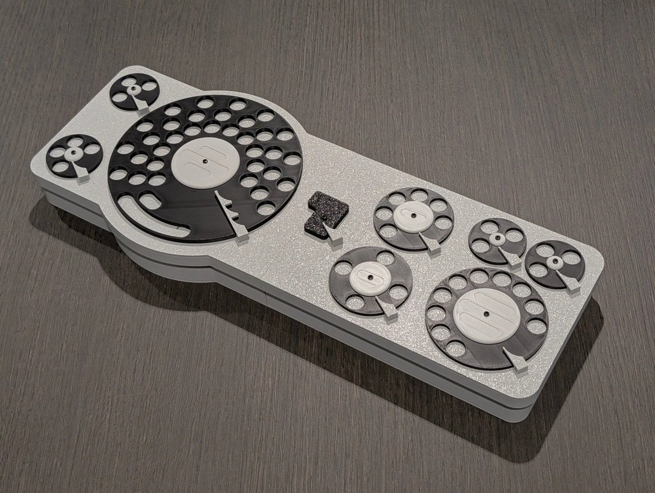
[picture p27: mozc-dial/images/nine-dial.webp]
9-Dial Edition


#### Required Parts

- 3D printed parts
  - 1 each of left and right bottom cases
  - 1 each of left and right top cases
  - 9 dials (including the enter key)
  - 9 dial caps
  - 5 types of encoders, 9 in total
    - 1 for 6 bits
    - 1 for 4 bits
    - 3 for 3 bits
    - 3 for 2 bits
    - 1 for 1 bit
  - 9 clutches
  - 2 types of fixing covers, 9 in total
    - 7 small
    - 2 large
  - 3 types of over-rotation prevention claws, 9 in total
    - 8 small
    - 1 triple
- 9 types of encoder patterns
- Screws
  - About 100 self-tapping screws, 2mm diameter, 4mm length
  - 18 washers
  - A few M3 bolts and nuts
- PCB
  - 11 sensor boards
  - 1 main board (assembled)
- Electronic parts ([see the board directory for details](./board/README.md))
  - 1 assembled main board with [2 firmware installed](./firmware/README.md)
  - 11 assembled sensor boards
  - 9 [Unipolar Stepping Motors 28BYJ-48 5V](https://akizukidenshi.com/catalog/g/g113256/)
  - Wiring materials: as needed

### Assembly

#### Step 1: Connect Left and Right

Connect the left and right bottom cases with four M3 screws.

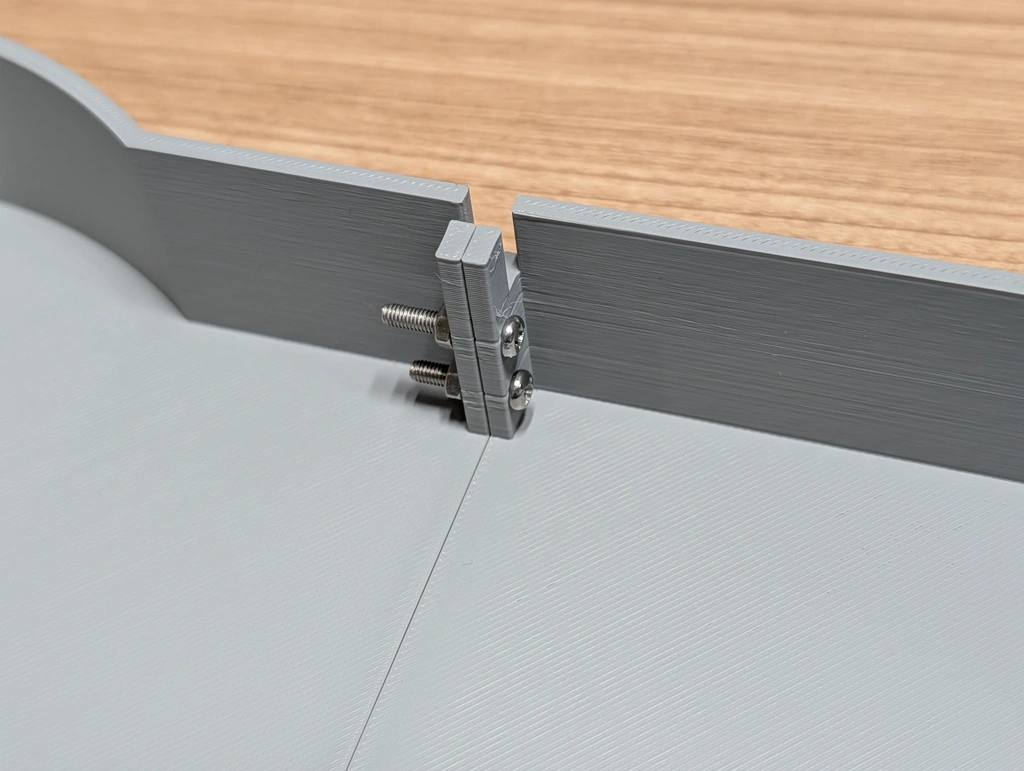
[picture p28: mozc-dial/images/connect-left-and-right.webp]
Connect left and right


#### Step 2: Create the Encoder

Same as the 1-dial edition.

#### Step 2: Assemble the Cover Module

Basically the same as the 1-dial edition.

Attach only one sensor board to seven of the covers.
Attach two sensor boards to two of the covers.

#### Step 3: Attach to the Case

Basically the same as the 1-dial edition.

#### Step 4: Wiring

Wire the motor and sensor board to the dedicated main board.

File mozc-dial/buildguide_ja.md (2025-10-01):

# ビルドガイド

Gboard DIY

[プロジェクトの概要を先にどうぞ](./README_ja.md)

## ファイル一覧

- stls/ : ケース用の STL ファイル
- stls/one_dial/ : 1ダイヤル版用
- stls/full/ : 9ダイヤル版用（準備中）
- pattern/ : エンコーダ用パーターンファイル
- board/ : KiCad用の回路図と基板のレイアウトデータ
- board/gerber/ : 基板製造用ガーバーデータと組み立て用の配置情報
- firmware/ : Raspberry Pi Pico C/C++ SDK向けファームウェア開発リソース一式
- firmware/prebuilt : コンパイル済みファームウェアバイナリ

## 組みたて

1ダイヤルのみ搭載し、組み立てやすくした、1ダイヤル版と、
9つのダイヤルを搭載した、フル版を用意しています。

### 1ダイヤル版

1ダイヤル版

#### 必要な部品

- 3Dプリント品(各1つ)
  - ケース下面(case_bottom.stl)
  - ケース上面(case_top.stl)
  - ダイヤル(dial.stl)
  - ダイヤルキャップ(dial_cap.stl)
  - エンコーダ(encoder.stl)
  - クラッチ(clutch.stl)
  - 固定用カバー(cover.stl 灰色など白に近い色で印刷)
  - 三連ツメ(end3.stl)
- エンコーダパターン pattern/one_dial.svg
- ねじ類
  - 直径2mm 長さ4mmのセルフタッピングスクリュー 12個
  - ワッシャー2個
- 電子部品([詳細についてはboardディレクトリを参照のこと](./board/README_ja.md))
  - [ファームウエア書き込み済み](./firmware/README_ja.md) Raspberry Pi Pico 1個
  - 組み立て済センサー基板 2枚
  - [ユニポーラー ステッピングモーター 28BYJ-48 5V](https://akizukidenshi.com/catalog/g/g113256/): 1個
  - [モータードライバーモジュール](https://www.aitendo.com/product/12366): 1個
  - 配線材: 適宜

#### Step 1: エンコーダの作成

[パターンファイル](./pattern/one_dial.svg)をコピー用紙に実寸大で印刷する。
印刷面を下にし上からエンコーダ部品をのりで貼り、周辺と中央をカットする。

エンコーダ部品にある◆マークと紙にある▼マークを合わせる。

マークをあわせる

組みあげたエンコーダ

#### Step 2: カバーモジュールの組み立て

カバーは、フォトセンサーを使う仕組み上、透過しない色で印刷する必要があります。
試作では灰色のPLAで印刷しました。
他の色の場合、センサ基板の抵抗値を調節する必要があるかもしれません。

裏面に、センサ基板2枚をネジ止めします。

同じく裏面にステッピングモータをネジ止めします。

モータに近い側の基板をセンサーL基板、もう1つの基板をセンサーH基板を呼びます。

裏面

表面に出てるモータ軸にクラッチをつけます。

表面

#### Step 3: ケースへの取りつけ

裏側から、エンコーダ、そしてカバーを取り付けます。
カバーの向きは下の写真を参考にしてください。

組みつけ

表から軸にダイヤルと、キャップをつけます。
ダイヤルと軸には小さいマークがあるので、マークをあわせます。

ダイヤルのマーク

上からダイヤルキャップをつけネジで止めます。

全体

#### Step 4: 配線

RaspberryPiPicoにセンサ基板とモータドライバをつけます。

配線

[詳細についてはboardディレクトリを参照のこと](./board/README_ja.md)

基板はケース底面の端に両面テープなどでとめておきます。

### 9ダイヤル版

**9ダイヤル版は現在調整中です。**

9ダイヤル版

#### 必要な部品

- 3Dプリント品
  - ケース下面 左右1つずつ
  - ケース上面 左右1つずつ
  - ダイヤル 9個 (エンターキーを含む)
  - ダイヤルキャップ 9個
  - エンコーダ 5種 計9個
    - 6ビット用 1個
    - 4ビット用 1個
    - 3ビット用 3個
    - 2ビット用 3個
    - 1ビット用 1個
  - クラッチ 9個
  - 固定カバー 2種 計9個
    - 小 7個
    - 大 2個
  - 回転しすぎ防止つめ 3種 9個
    - 小 8個
    - 3連 1個
- エンコーダパターン 9種類
- ねじ類
  - 直径2mm 長さ4mmのセルフタッピングスクリュー 約100個
  - ワッシャー 18個
  - M3ボルトとナット 少々
- 電子部品([詳細については基板組み立てガイドを参照のこと](./board/README_ja.md))
  - 組み立て[ファームウエア書き込み](./firmware/README_ja.md)済みメイン基板 1枚
  - 組み立て済センサー基板 11枚
  - [ユニポーラー ステッピングモーター 28BYJ-48 5V](https://akizukidenshi.com/catalog/g/g113256/): 9個
  - 配線材: 適宜

#### Step 1: 左右の接続

ケース下面の左右をM3ねじ4本で接続します。

左右接続

#### Step 2: エンコーダの作成

1ダイヤル版と同様です。

#### Step 2: カバーモジュールの組み立て

基本的には1ダイヤル版と同様です。

カバーのうち7つは、センサ基板を1枚だけ組みつけます。
2つは、センサ基板を2枚つけます。

#### Step 3: ケースへの取りつけ

基本的には1ダイヤル版と同様です。

#### Step 4: 配線

専用のメイン基板に、モータとセンサ基板を配線します。

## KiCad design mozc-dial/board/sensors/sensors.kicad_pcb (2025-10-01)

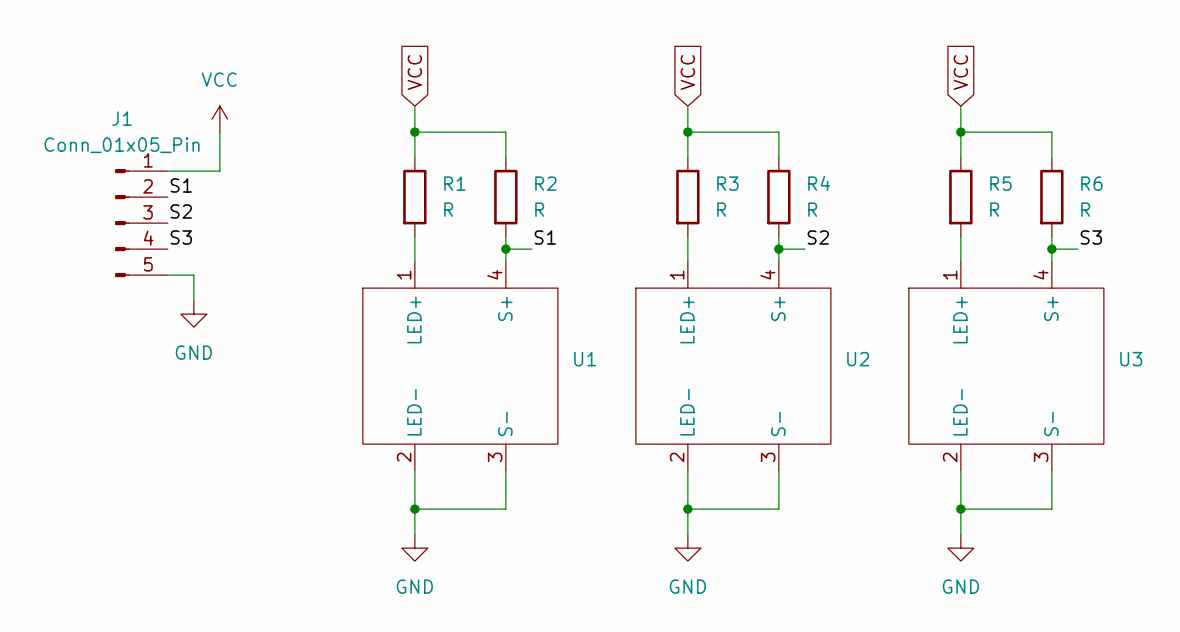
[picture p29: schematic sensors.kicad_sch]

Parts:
J1: Conn_01x05_Pin; PinHeader_1x05_P2.54mm_Vertical
R1, R2, R3, R4, R5, R6: R; Registor
U1, U2, U3: RPR220

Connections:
/S1: J1.2, R2.2, U1.4 (S+)
/S2: J1.3, R4.2, U2.4 (S+)
/S3: J1.4, R6.2, U3.4 (S+)
GND: J1.5, U1.2 (LED-), U1.3 (S-), U2.2 (LED-), U2.3 (S-), U3.2 (LED-), U3.3 (S-)
unnamed: R1.2, U1.1 (LED+)
unnamed: R3.2, U2.1 (LED+)
unnamed: R5.2, U3.1 (LED+)
VCC: J1.1, R1.1, R2.1, R3.1, R4.1, R5.1, R6.1

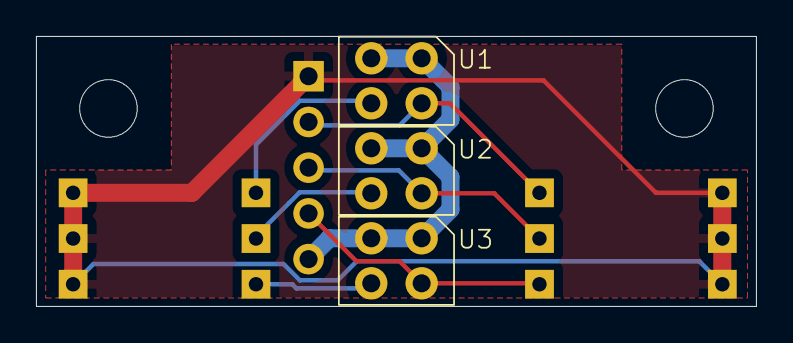
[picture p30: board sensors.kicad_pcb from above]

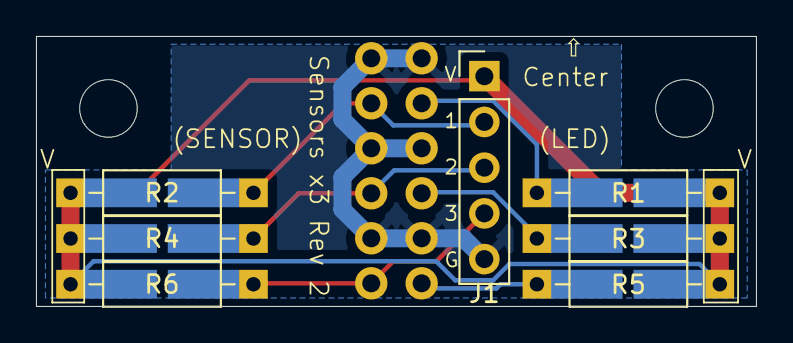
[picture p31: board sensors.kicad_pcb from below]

Board: 2 copper layers, 40.0 x 15.0 mm, 12 parts (7 on the bottom side), 8 nets.

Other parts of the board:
REF1, REF2: MountingHole_3.2mm_M3

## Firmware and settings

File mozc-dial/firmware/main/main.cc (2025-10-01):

// Copyright 2025 Google Inc.
// Use of this source code is governed by an Apache License that can be found
// in the LICENSE file.

#include <array>
#include <cstdint>
#include <cstdio>
#include <vector>

#include "hardware/uart.h"
#if LIB_PICO_STDIO_UART
#include "pico/stdio_uart.h"
#endif
#include "pico/stdlib.h"

#include "../common/dial_controller.h"
#include "../common/motor_controller.h"
#include "../common/photo_sensor.h"
#include "../common/usage_tables.h"
#include "../common/usb_hid_keyboard.h"
#include "i2c_controller.h"

int main() {
#if LIB_PICO_STDIO_UART
  stdio_uart_init_full(uart0, /*baud_rate=*/115200, /*tx_pin=*/0,
                       /*rx_pin=*/-1);
#else
  stdio_init_all();
#endif

  I2CController i2c(i2c0, /*sda=*/28, /*scl=*/29);

  // Sensor A, B, C, D, E, F, G, I (note: H is missing here as it's accessed via
  // I2C)
  std::array<PhotoSensor, 8> sensors = {
      PhotoSensor(1, 2, 3, 4, 5, 6),  // A
      PhotoSensor(7, 8),              // B
      PhotoSensor(9, 10, 11),         // C
      PhotoSensor(12, 13),            // D (3 sensors are implemented, but...)
      PhotoSensor(15, 16, 17),        // E
      PhotoSensor(18, 19, 20),        // F
      PhotoSensor(21, 22),            // G (3 sensors are implemented, but...)
      PhotoSensor(24, 25, 26, 27),    // I
  };

  std::array<DialController, 9> dials = {
      DialController(),  // A
      DialController(),  // B
      DialController(),  // C
      DialController(),  // D
      DialController(),  // E
      DialController(),  // F
      DialController(),  // G
      DialController(),  // I

      DialController(),  // H
  };

  std::array<const std::vector<uint8_t>*, 9> usages = {
      &usage_tables::a,  // A
      &usage_tables::b,  // B
      &usage_tables::c,  // C
      &usage_tables::d,  // D
      &usage_tables::e,  // E
      &usage_tables::f,  // F
      &usage_tables::g,  // G
      &usage_tables::i,  // I

      &usage_tables::h,  // H
  };

  std::array<const std::vector<uint8_t>*, 9> fn_usages = {
      &usage_tables::fn_a,  // A
      &usage_tables::fn_b,  // B
      &usage_tables::fn_c,  // C
      &usage_tables::fn_d,  // D
      &usage_tables::fn_e,  // E
      &usage_tables::fn_f,  // F
      &usage_tables::fn_g,  // G
      &usage_tables::fn_i,  // I

      &usage_tables::fn_h,  // H
  };

  std::array<const std::vector<uint8_t>*, 9> modifiers = {
      &usage_tables::modifier_a,  // A
      &usage_tables::modifier_b,  // B
      &usage_tables::modifier_c,  // C
      &usage_tables::modifier_d,  // D
      &usage_tables::modifier_e,  // E
      &usage_tables::modifier_f,  // F
      &usage_tables::modifier_g,  // G
      &usage_tables::modifier_i,  // I

      &usage_tables::modifier_h,  // H
  };

  UsbHidKeyboard usb_hid_keyboard(
      /*vendor_id=*/0x6666, /*product_id=*/0x2025,
      /*version=*/0x0109, /*vendor_name=*/"Gboard DIY prototype",
      /*product_name=*/"Gboard Dial version", /*version_name=*/"9 Dial");
  usb_hid_keyboard.SetAutoKeyRelease(true);

  // Wait for a while, just in case, so that the sub-controller can be ready on
  // I2C.
  sleep_ms(100);

  std::vector<uint8_t> i2c_buffer(2);
  bool fn = false;

  while (true) {
    uint16_t motor_start_bitmap = 0;
    for (size_t i = 0; i < sensors.size(); ++i) {
      dials[i].Update(sensors[i].Read());
      if (!dials[i].IsBasePosition()) {
        motor_start_bitmap |= (1 << i);
      }
    }
    // Read the remote sensor H value via I2C.
    bool rc = i2c.Read(68, 0, std::span<uint8_t>({i2c_buffer.data(), 1}));
    if (rc) {
      dials[8].Update(i2c_buffer[0]);
      if (!dials[8].IsBasePosition()) {
        motor_start_bitmap |= (1 << 8);
      }
    }

    // Drive all motors via I2C.
    i2c_buffer[0] = motor_start_bitmap & 0xff;
    i2c_buffer[1] = motor_start_bitmap >> 8;
    rc = i2c.Write(68, 0, i2c_buffer);

    // Check all dials to see if we have pending inputs to send over USB HID.
    for (size_t i = 0; i < dials.size(); ++i) {
      // `decided_position` is std::nullopt while the dial is not moved at the
      // base position, or moving. But once it returns to the base position from
      // non-base positions, it will have a 1 or a larger value that indicates
      // the position where the dial starts returning.
      std::optional<uint8_t> decided_position = dials[i].PopDecidedPosition();
      if (!decided_position) {
        continue;
      }
      // One-time flip to use an alternative set of usages, by the Fn key.
      std::array<const std::vector<uint8_t>*, 9>& current_usages =
          fn ? fn_usages : usages;

      // Adjust the index as it is 1-based.
      size_t index = *decided_position - 1;

      if (index < current_usages[i]->size()) {
        uint8_t usage = (*current_usages[i])[index];
        if (usage) {
          usb_hid_keyboard.PressByUsageId(usage);
          fn = false;
        }
      }
      if (index < modifiers[i]->size()) {
        uint8_t modifier = (*modifiers[i])[index];
        if (modifier == usage_tables::kModifierLeftGUI) {
          // This device interprets the left GUI key as a one-time keymap
          // alternate key instead of the normal GUI modifier key use.
          fn = true;
        } else {
          usb_hid_keyboard.SetModifiers(
              (usb_hid_keyboard.GetModifiers() | modifier));
        }
      }
    }
  }
}

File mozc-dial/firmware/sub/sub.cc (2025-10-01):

// Copyright 2025 Google Inc.
// Use of this source code is governed by an Apache License that can be found
// in the LICENSE file.

#include <cstdio>

#include "hardware/uart.h"
#include "pico/stdio.h"
#if LIB_PICO_STDIO_UART
#include "pico/stdio_uart.h"
#endif

#include "../common/motor_controller.h"
#include "../common/photo_sensor.h"
#include "i2c_device.h"

namespace {

MotorController motor_controller;
PhotoSensor sensor_h(26, 27);

uint8_t i2c_reader(uint8_t address) {
  switch (address) {
    case 0:  // Read Sensor H
      return sensor_h.Read();
    default:
      return 0xff;
  }
}

void i2c_writer(uint8_t address, uint8_t value) {
  switch (address) {
    case 0:  // Set Motor 1-8 State
      for (uint8_t motor = 0; motor < 8; ++motor) {
        if (value & (1 << motor)) {
          motor_controller.Start(motor);
        } else {
          motor_controller.Stop(motor);
        }
      }
      break;
    case 1:  // Set Motor 9 State
      if (value & 1) {
        motor_controller.Start(8);
      } else {
        motor_controller.Stop(8);
      }
      break;
  }
}

}  // namespace

int main() {
#if LIB_PICO_STDIO_UART
  // Customized initialization to use only GPIO 0 for TX.
  stdio_uart_init_full(uart0, /*baud_rate=*/115200, /*tx_pin=*/0,
                       /*rx_pin=*/-1);
#else
  stdio_init_all();
#endif

  I2CDevice i2c(/*i2c=*/i2c0, /*sda=*/28, /*scl=*/29, /*address=*/68);
  i2c.SetReadHandler(i2c_reader);
  i2c.SetWriteHandler(i2c_writer);

  while (true) {
    tight_loop_contents();
  }
}

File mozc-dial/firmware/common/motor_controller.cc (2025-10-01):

// Copyright 2025 Google Inc.
// Use of this source code is governed by an Apache License that can be found
// in the LICENSE file.

#include "motor_controller.h"

#include <cstdio>
#include <initializer_list>

#include "hardware/gpio.h"
#include "pico/time.h"

static constexpr int kMotorStepIntervalInUs = 2000;

// Activate 1 of 8 motor drivers in a specific step phase.
class MotorController::Decoder {
 public:
  Decoder(int8_t a0, int8_t a1, int8_t a2, int8_t en)
      : a0_(a0), a1_(a1), a2_(a2), en_(en) {
    for (int8_t gpio : {en, a0, a1, a2}) {
      gpio_init(gpio);
      gpio_set_dir(gpio, GPIO_OUT);
      gpio_put(gpio, false);
    }
  }
  Decoder(const Decoder&) = delete;
  Decoder& operator=(const Decoder&) = delete;
  ~Decoder() = default;

  void Select(uint8_t index) {
    hard_assert(index < 8);
    gpio_put(a0_, index & 1);
    gpio_put(a1_, index & 2);
    gpio_put(a2_, index & 4);
    gpio_put(en_, true);
  }
  void Unselect() { gpio_put(en_, false); }

 private:
  int8_t a0_;
  int8_t a1_;
  int8_t a2_;
  int8_t en_;
};

// static
bool MotorController::OnAlarm(repeating_timer* t) {
  static_cast<MotorController*>(t->user_data)->Step();
  return true;
}

MotorController::MotorController(Mode mode) {
  if (mode == Mode::k9Motor) {
    // Each decoder is responsible for a specific phase to driver 1 of 8 motor
    // drivers. As we have 4 phases, it can drive 4 motors at the same time, and
    // by time division multiplexing, we make them drive 8 motors.
    decoder_[0] = std::make_unique<Decoder>(1, 2, 3, 4);
    decoder_[1] = std::make_unique<Decoder>(5, 6, 7, 8);
    decoder_[2] = std::make_unique<Decoder>(9, 10, 11, 12);
    decoder_[3] = std::make_unique<Decoder>(13, 14, 15, 16);
  }

  // 9th motor driver is controlled via GPIOs directly.
  for (int8_t gpio : {17, 18, 19, 20}) {
    gpio_init(gpio);
    gpio_set_dir(gpio, GPIO_OUT);
    gpio_put(gpio, false);
  }

  add_repeating_timer_us(-kMotorStepIntervalInUs, OnAlarm, this, &timer_);
}

MotorController::~MotorController() {}

void MotorController::Start(uint8_t index) {
  hard_assert(index < kNumOfMotors);
  started_[index] = true;
}

void MotorController::Stop(uint8_t index) {
  hard_assert(index < kNumOfMotors);
  started_[index] = false;
}

void MotorController::Step() {
  // Drive first 4 motor drivers in even phases, and later 4 ones in odd
  // phases.
  size_t start_index = (phase_ & 1) ? kNumOfPhases : 0;
  size_t half_phase = phase_ >> 1;
  for (size_t i = start_index; i < start_index + kNumOfPhases; ++i) {
    if (!decoder_[i]) {
      continue;
    }
    if (started_[i]) {
      decoder_[(i + half_phase) % kNumOfPhases]->Select(i);
    } else {
      decoder_[(i + half_phase) % kNumOfPhases]->Unselect();
    }
  }
  // Drive the last 9th motor drivers.
  bool on = started_[8] && phase_ & 1;
  gpio_put(17, on && half_phase == 0);
  gpio_put(18, on && half_phase == 1);
  gpio_put(19, on && half_phase == 2);
  gpio_put(20, on && half_phase == 3);

  phase_ = (phase_ + 7) % 8;
}

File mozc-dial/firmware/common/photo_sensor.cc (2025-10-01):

// Copyright 2025 Google Inc.
// Use of this source code is governed by an Apache License that can be found
// in the LICENSE file.

#include "photo_sensor.h"

#include "hardware/gpio.h"

PhotoSensor::PhotoSensor(int8_t bit0,
                         int8_t bit1,
                         int8_t bit2,
                         int8_t bit3,
                         int8_t bit4,
                         int8_t bit5)
    : bits({bit0, bit1, bit2, bit3, bit4, bit5}) {
  for (int8_t gpio : bits) {
    gpio_init(gpio);
    gpio_set_dir(gpio, GPIO_IN);
    gpio_pull_up(gpio);  // Built-in 50-80K pull-up
  }
}

uint8_t PhotoSensor::Read() {
  uint8_t value = 0;
  for (size_t bit = 0; bit < bits.size(); ++bit) {
    if (bits[bit] == kNotUsed) {
      break;
    }
    value |= gpio_get(bits[bit]) ? (1 << bit) : 0;
  }
  return value;
}
